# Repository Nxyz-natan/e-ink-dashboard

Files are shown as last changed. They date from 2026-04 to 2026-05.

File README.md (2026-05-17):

# e-ink-dashboard
e ink dashboard for me to display weather my room temp calander and date and time and disply my spotify 

Hardware Design

I designed a custom PCB that integrates:
ESP32-S3 microcontroller
BME280 sensor
Power management (voltage regulator + charging IC)
USB-C input
Display connector

Features

Real-time weather display
displays whats spotify playing
Room temperature and humidity using BME280 sensor
Calendar, date, and time display
Low power consumption using e-ink technology

here is my schematics 
Screenshot 2026-04-18 at 7 24 58 PM
here my pcb
Screenshot 2026-04-18 at 7 25 20 PM
here is my case 
Screenshot 2026-04-18 at 7 25 42 PM
## Bill of Materials

| Name | Purpose | Qty | Total Cost (USD) | Distributor |
|---|---|-----|---|---|
| 7.3" E Ink Spectra 6 Display 800x480 | Display | 1 | $47.34 | Good Display |
| Resistor 4.7kΩ 0402 | Resistor | 100 | $0.08 | LCSC |
| Pin Socket 1×08 2.54mm | Socket | 5 | $0.53 | LCSC |
|pcb | pcb | 5 | 3.50$ | jlcp |
| Switch 6×6×5mm | Button | 5 | $0.36 | LCSC |
| Resistor 1.2kΩ 0402 | Resistor | 100 | $0.09 | LCSC |
| BME280 | Temp/humidity sensor | 1 | $7.42 | LCSC |
| ME6211C33M5G-N | Voltage regulator | 10 | $0.50 | LCSC |
| TP4056-42-ESOP8 | Battery charger IC | 5 | $0.93 | LCSC |
| ESP32-S3-WROOM-1-N16R8 | MCU | 1 | $5.21 | LCSC |

**Total with shipping: 95.85$**

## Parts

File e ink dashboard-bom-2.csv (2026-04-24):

Name | Purpose | Quantity | Total Cost (USD) | Link | Distributor
3d printer | case |  | 15.00 |  | hackclub
pcb | pcb |  | 3.50 |  | jlcpcb
7.3-Inch Full Color E Ink Spectra 6 Display High-saturation 800x480 GDEP073E01 | display |  | 47.34 |  | good display
Switch 6x6x5mm | button | 5 | 0.36 |  | lcsc
ESP32-S3 N16R8 | chip | 1 | 5.21 |  | lcsc
Resistor 1.2kΩ 0402 | Resistor | 100 | 0.09 |  | lcsc
ME6211C33M5G-N | voltage regulator | 10 | 0.50 |  | lcsc
TP4056-42-ESOP8 | battery charger IC | 5 | 0.93 |  | lcsc
BME280 | temp reader | 1 | 7.42 |  | lcsc
Resistor 4.7kΩ 0402 | Resistor | 100 | 0.08 |  | lcsc
Pin Socket 1x08 2.54mm | Socket | 5 | 0.53 |  | lcsc

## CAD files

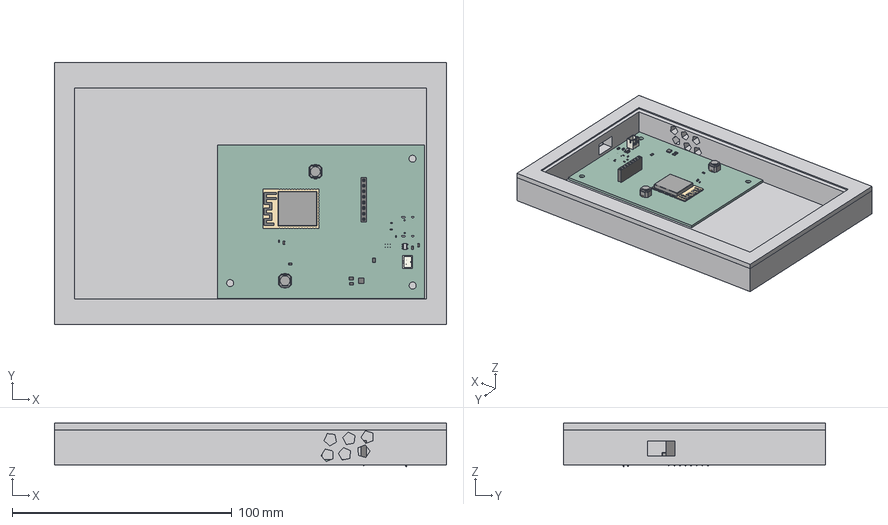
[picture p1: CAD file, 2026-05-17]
cad/e ink dahsboard lid with out a screen.step
178.2 x 119.2 x 19.8 mm
R_0402_1005Metric x 2
C_0402_1005Metric x 2
PinSocket_1x08_P2.54mm_Vertical x 3
R_0805_2012Metric x 27
SOT-23-5 x 5
pin_1 x 10
pin_2 x 10
JST_PH_B2B-PH-K_1x02_P2.00mm_Vertical x 5
C_0603_1608Metric x 3
ESP32-S3-WROOM-1 x 5
R_0603_1608Metric
Bosch_LGA-8_2.5x2.5mm_P0.65mm_ClockwisePinNumbering x 5
e-ink dashboard_PCB x 5
C_0805_2012Metric x 20
PinHeader_1x08_P2.54mm_Vertical x 2

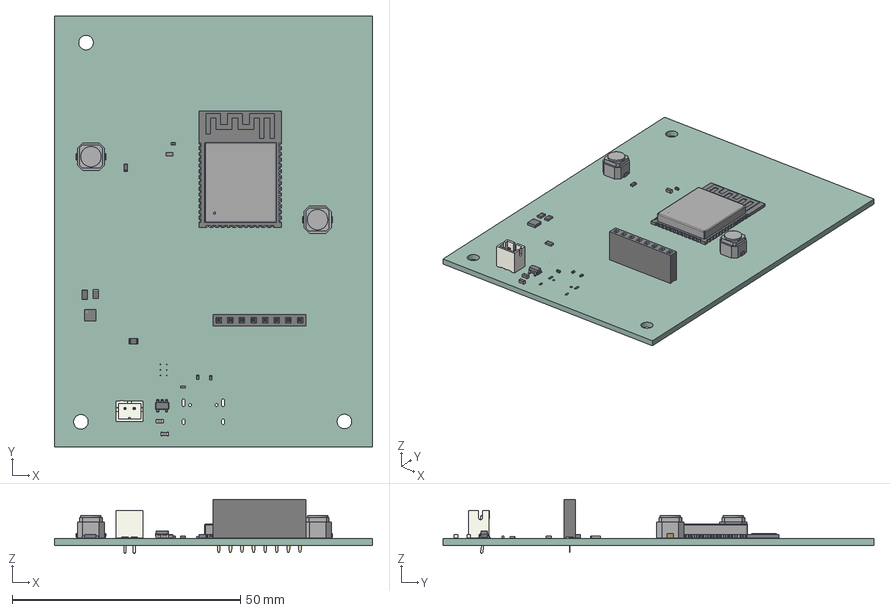
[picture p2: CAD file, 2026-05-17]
cad/pcbeink.step
69.6 x 94.2 x 11.9 mm
R_0402_1005Metric x 2
C_0402_1005Metric x 2
PinSocket_1x08_P2.54mm_Vertical
R_0805_2012Metric x 3
SOT-23-5
pin_1 x 2
pin_2 x 2
JST_PH_B2B-PH-K_1x02_P2.00mm_Vertical
C_0603_1608Metric x 3
ESP32-S3-WROOM-1
R_0603_1608Metric
Bosch_LGA-8_2.5x2.5mm_P0.65mm_ClockwisePinNumbering
e-ink dashboard_PCB

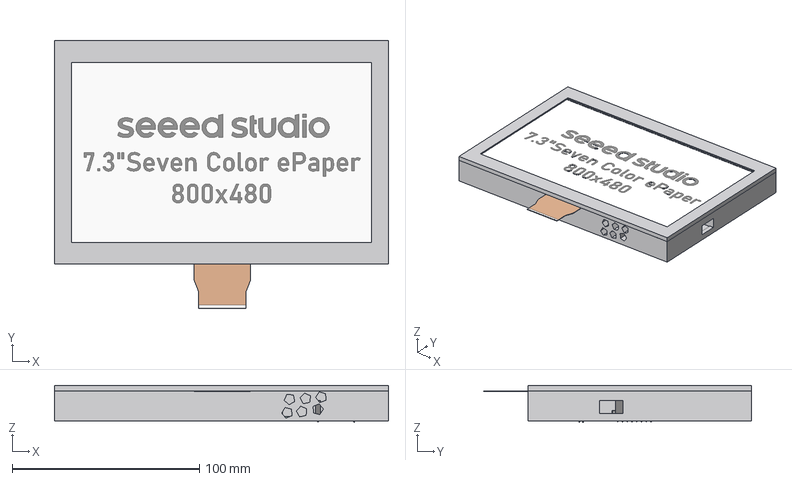
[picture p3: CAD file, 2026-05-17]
cad/e ink dahsboard with screen.step
178.2 x 142.8 x 19.8 mm
R_0402_1005Metric x 2
C_0402_1005Metric x 2
PinSocket_1x08_P2.54mm_Vertical x 3
R_0805_2012Metric x 27
SOT-23-5 x 5
pin_1 x 10
pin_2 x 10
JST_PH_B2B-PH-K_1x02_P2.00mm_Vertical x 5
C_0603_1608Metric x 3
ESP32-S3-WROOM-1 x 5
R_0603_1608Metric
Bosch_LGA-8_2.5x2.5mm_P0.65mm_ClockwisePinNumbering x 5
e-ink dashboard_PCB x 5
C_0805_2012Metric x 20
PinHeader_1x08_P2.54mm_Vertical x 2

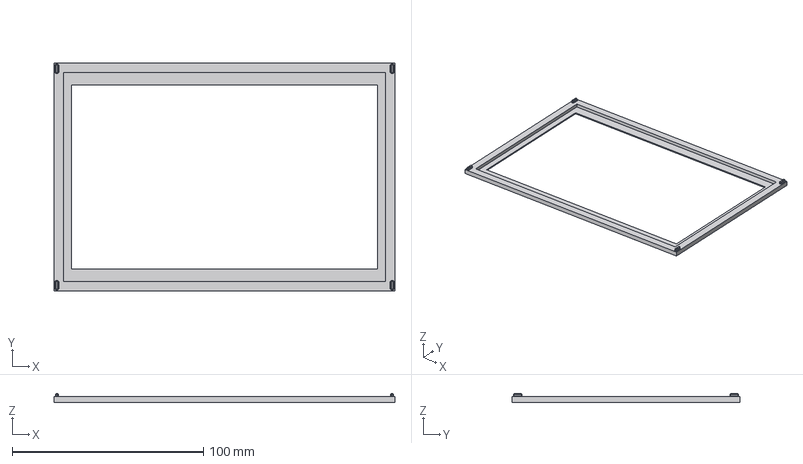
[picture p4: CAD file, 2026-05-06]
cad/e ink dahsboard lid.step
178.2 x 119.2 x 4.50 mm
R_0805_2012Metric x 12
C_0805_2012Metric x 10
PinSocket_1x08_P2.54mm_Vertical
SOT-23-5 x 2
pin_1 x 4
pin_2 x 4
JST_PH_B2B-PH-K_1x02_P2.00mm_Vertical x 2
ESP32-S3-WROOM-1 x 2
Bosch_LGA-8_2.5x2.5mm_P0.65mm_ClockwisePinNumbering x 2
e-ink dashboard_PCB x 2
PinHeader_1x08_P2.54mm_Vertical

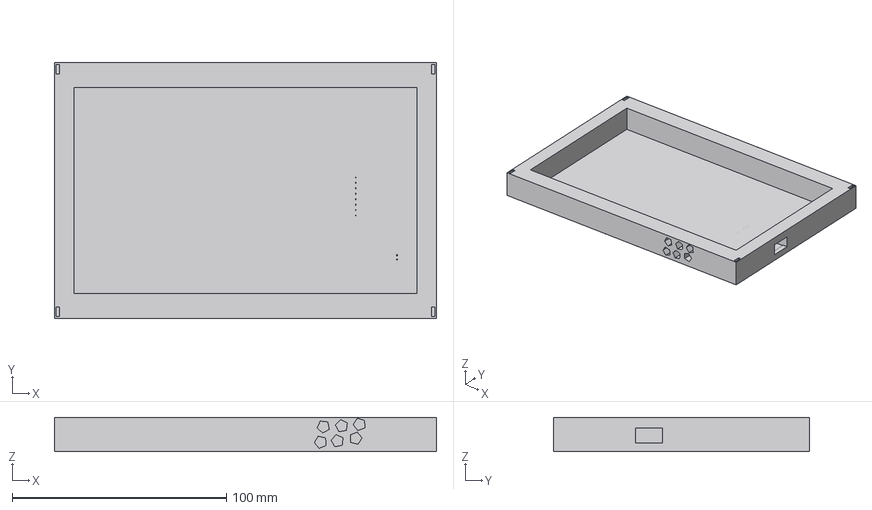
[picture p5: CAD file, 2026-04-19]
cad/case e ink.step
178.2 x 119.2 x 16.0 mm
R_0805_2012Metric x 12
C_0805_2012Metric x 10
PinSocket_1x08_P2.54mm_Vertical
SOT-23-5 x 2
pin_1 x 4
pin_2 x 4
JST_PH_B2B-PH-K_1x02_P2.00mm_Vertical x 2
ESP32-S3-WROOM-1 x 2
Bosch_LGA-8_2.5x2.5mm_P0.65mm_ClockwisePinNumbering x 2
e-ink dashboard_PCB x 2
PinHeader_1x08_P2.54mm_Vertical

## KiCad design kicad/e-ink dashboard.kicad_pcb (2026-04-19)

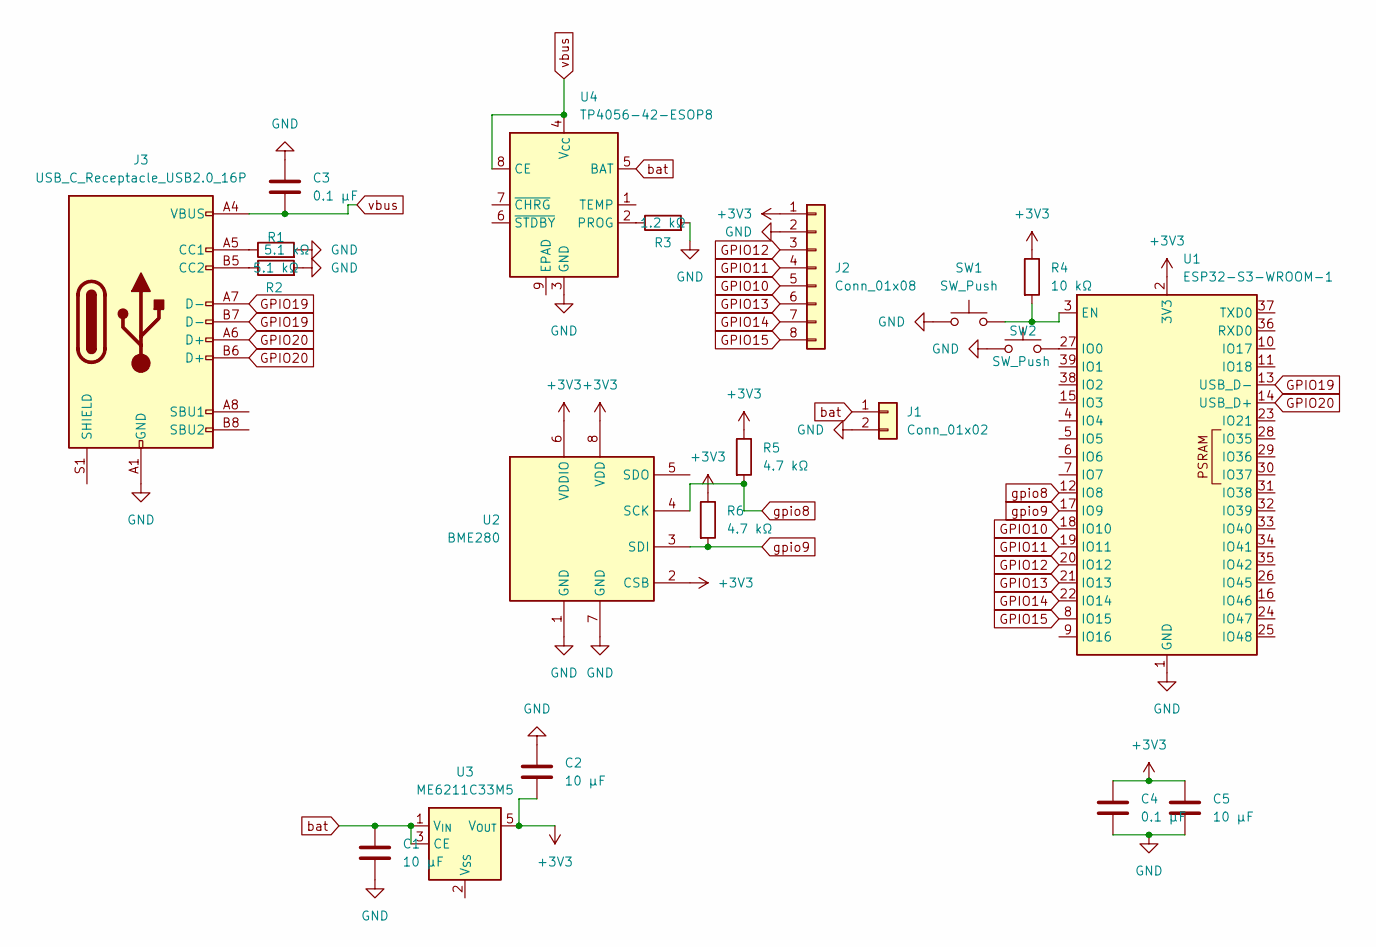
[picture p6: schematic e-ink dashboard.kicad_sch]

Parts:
C1, C2, C5: 10 µF; C_0603_1608Metric
C3, C4: 0.1 µF; C_0402_1005Metric
J1: Conn_01x02; JST_PH_B2B-PH-K_1x02_P2.00mm_Vertical
J2: Conn_01x08; PinSocket_1x08_P2.54mm_Vertical
J3: USB_C_Receptacle_USB2.0_16P; USB_C_Receptacle_HRO_TYPE-C-31-M-12
R1, R2: 5.1 kΩ; R_0402_1005Metric
R3: 1.2 kΩ; R_0805_2012Metric
R4: 10 kΩ; R_0603_1608Metric
R5, R6: 4.7 kΩ; R_0805_2012Metric
SW1, SW2: SW_Push; SW_Push_1TS009xxxx-xxxx-xxxx_6x6x5mm
U1: ESP32-S3-WROOM-1
U2: BME280; Bosch_LGA-8_2.5x2.5mm_P0.65mm_ClockwisePinNumbering
U3: ME6211C33M5; SOT-23-5
U4: TP4056-42-ESOP8; SOIC-8-1EP_3.9x4.9mm_P1.27mm_EP2.41x3.3mm_ThermalVias

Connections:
+3V3: C2.2, C4.1, C5.1, J2.1, R4.1, R5.1, R6.1, U1.2 (3V3), U2.2 (CSB), U2.6 (VDDIO), U2.8 (VDD), U3.5 (V_{OUT})
GND: C1.1, C2.1, C3.1, C4.2, C5.2, J1.2, J2.2, J3.A1 (GND), J3.A12 (GND), J3.B1 (GND), J3.B12 (GND), R1.2, R2.2, R3.2, SW1.1, SW2.1, U1.1 (GND), U1.40 (GND), U1.41 (GND), U2.1 (GND), U2.7 (GND), U4.3 (GND)
GPIO10: J2.5, U1.18 (IO10)
GPIO11: J2.4, U1.19 (IO11)
GPIO12: J2.3, U1.20 (IO12)
GPIO13: J2.6, U1.21 (IO13)
GPIO14: J2.7, U1.22 (IO14)
GPIO15: J2.8, U1.8 (IO15)
GPIO19: J3.A7 (D-), J3.B7 (D-), U1.13 (USB_D-)
GPIO20: J3.A6 (D+), J3.B6 (D+), U1.14 (USB_D+)
unnamed: J3.A5 (CC1), R1.1
unnamed: J3.B5 (CC2), R2.1
unnamed: R4.2, SW1.2, U1.3 (EN)
unnamed: SW2.2, U1.27 (IO0)
unnamed: R3.1, U4.2 (PROG)
bat: C1.2, J1.1, U3.1 (V_{IN}), U3.3 (CE), U4.5 (BAT)
gpio8: R5.2, U1.12 (IO8), U2.4 (SCK)
gpio9: R6.2, U1.17 (IO9), U2.3 (SDI)
vbus: C3.2, J3.A4 (VBUS), J3.A9 (VBUS), J3.B4 (VBUS), J3.B9 (VBUS), U4.4 (V_{CC}), U4.8 (CE)

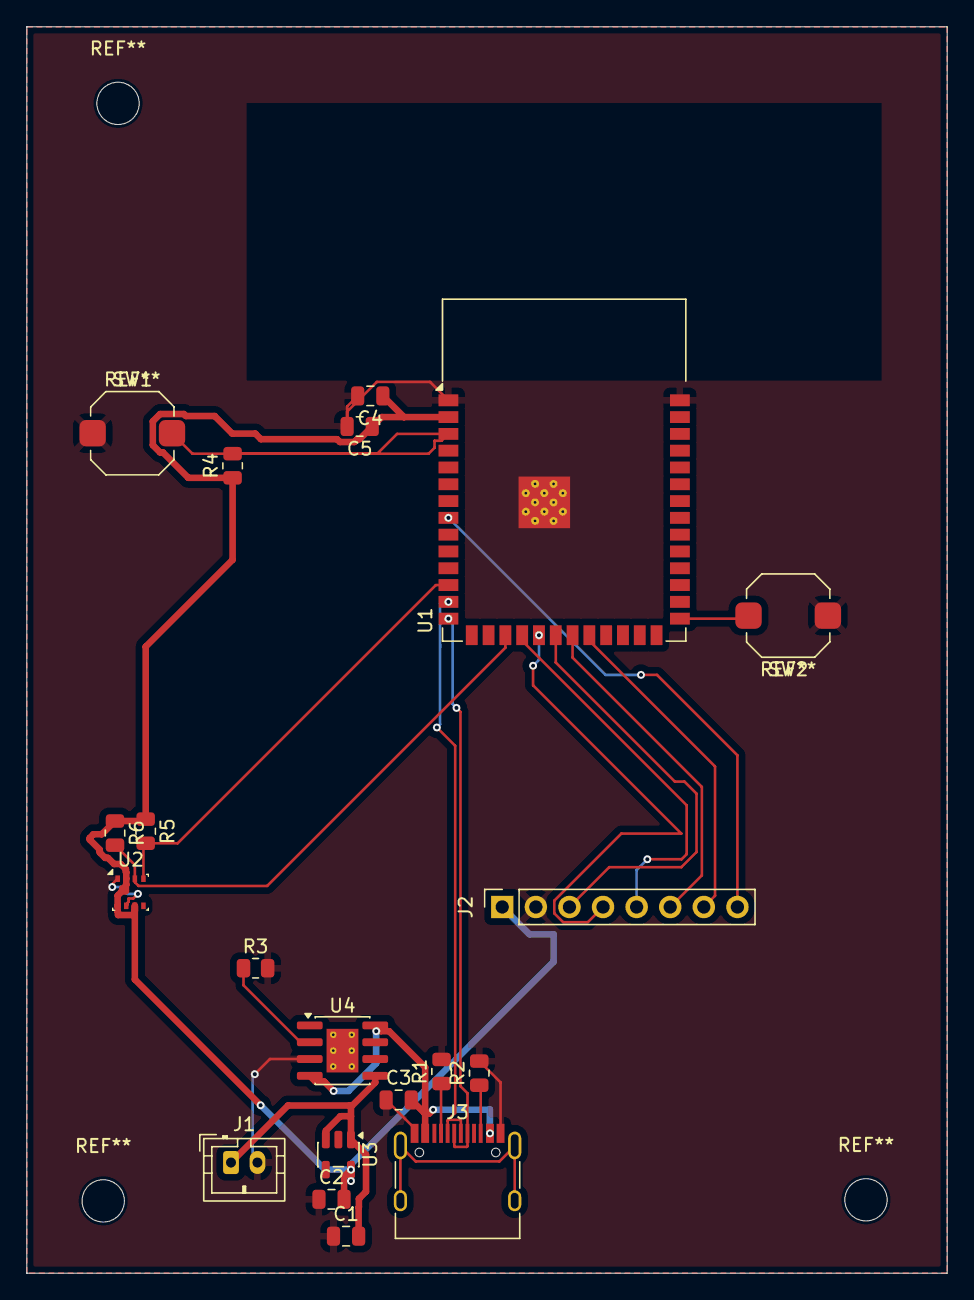
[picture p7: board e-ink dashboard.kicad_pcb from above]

Board: 2 copper layers, 69.6 x 94.2 mm, 20 parts (0 on the bottom side), 19 nets.

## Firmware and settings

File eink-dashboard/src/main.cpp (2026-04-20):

#include <Arduino.h>
#include <WiFi.h>
#include <SPI.h>
#include <time.h>

#include "config.h"
#include "display_driver.h"
#include "weather.h"
#include "spotify.h"

// Global objects
EpaperDisplay display;
WeatherClient weather(WEATHER_API_KEY, WEATHER_CITY, WEATHER_COUNTRY);
SpotifyClient spotify(SPOTIFY_CLIENT_ID, SPOTIFY_CLIENT_SECRET);

// Timing
unsigned long lastWeatherUpdate = 0;
unsigned long lastSpotifyUpdate = 0;
unsigned long lastClockUpdate = 0;
unsigned long lastFullRefresh = 0;

// State tracking
bool nothingPlaying = false;
const unsigned long FULL_REFRESH_INTERVAL = 300000;  // Full refresh every 5 min

void connectWiFi() {
    Serial.println("Connecting to WiFi...");
    WiFi.begin(WIFI_SSID, WIFI_PASSWORD);

    int attempts = 0;
    while (WiFi.status() != WL_CONNECTED && attempts < 30) {
        delay(500);
        Serial.print(".");
        attempts++;
    }

    if (WiFi.status() == WL_CONNECTED) {
        Serial.println("\nWiFi connected!");
        Serial.println("IP: " + WiFi.localIP().toString());
    } else {
        Serial.println("\nWiFi connection failed!");
    }
}

void syncTime() {
    configTime(0, 0, NTP_SERVER);
    setenv("TZ", TIMEZONE, 1);
    tzset();

    struct tm timeinfo;
    int attempts = 0;
    while (!getLocalTime(&timeinfo) && attempts < 10) {
        delay(500);
        attempts++;
    }
}

String formatTime(time_t now) {
    char buffer[6];
    struct tm* timeinfo = localtime(&now);
    strftime(buffer, 6, "%H:%M", timeinfo);
    return String(buffer);
}

String formatDate(time_t now) {
    char buffer[20];
    struct tm* timeinfo = localtime(&now);
    strftime(buffer, 20, "%A, %b %d", timeinfo);
    return String(buffer);
}

void drawClock(time_t now) {
    auto* g = display.getDisplay();
    // Large clock centered
    g->setFont(&FreeMonoBold24pt7b);
    g->setCursor(50, 100);
    g->print(formatTime(now));

    g->setFont(&FreeMono12pt7b);
    g->setCursor(50, 145);
    g->print(formatDate(now));

    // Separator line
    g->drawLine(50, 160, 750, 160, GxEPD2_3C::BLACK);
}

void drawWeather() {
    auto* g = display.getDisplay();
    g->setFont(&FreeMonoBold12pt7b);
    g->setCursor(50, 200);
    g->print("Weather");

    if (weather.isValid()) {
        WeatherData data = weather.getData();
        g->setFont(&FreeMono18pt7b);
        g->setCursor(50, 250);
        g->print(data.temperature, 0);
        g->print(" C");

        g->setFont(&FreeMono9pt7b);
        g->setCursor(200, 255);
        g->println(data.description);

        g->setCursor(50, 285);
        g->print("Humidity: ");
        g->print(data.humidity);
        g->print("%  |  Wind: ");
        g->println(data.windSpeed);
    } else {
        g->setFont(&FreeMono9pt7b);
        g->setCursor(50, 250);
        g->println("Loading...");
    }
}

void drawSpotify() {
    auto* g = display.getDisplay();
    g->setFont(&FreeMonoBold12pt7b);
    g->setCursor(50, 340);
    g->print("Now Playing");

    if (spotify.isValid()) {
        SpotifyData data = spotify.getData();
        g->setFont(&FreeMono12pt7b);
        g->setCursor(50, 385);
        g->print(data.isPlaying ? "> " : "|| ");
        g->println(data.trackName);

        g->setFont(&FreeMono9pt7b);
        g->setCursor(70, 415);
        g->print("by ");
        g->println(data.artistName);
    } else {
        g->setFont(&FreeMono9pt7b);
        g->setCursor(50, 385);
        g->println("No playback");
    }
}

void drawCalendar() {
    // Placeholder - calendar skipped for now
    // Could add quotes, stock ticker, or other info here
}

void drawFullDisplay() {
    display.clear();

    time_t now = time(nullptr);
    drawClock(now);
    drawWeather();
    drawSpotify();

    display.display();
}

void setup() {
    Serial.begin(115200);
    Serial.println("E-Ink Dashboard Starting...");

    // Initialize display
    Serial.println("Initializing display...");
    display.begin();
    display.setRotation(1);  // Landscape orientation
    display.setFullWindow();

    // Connect to WiFi
    connectWiFi();

    // Sync time
    syncTime();

    // Initial updates
    Serial.println("Performing initial updates...");
    weather.update();
    spotify.update();

    // Draw everything
    drawFullDisplay();

    lastFullRefresh = millis();
    Serial.println("Setup complete!");
}

void loop() {
    unsigned long now = millis();
    bool needsRefresh = false;

    // Weather update (every 15 min)
    if (now - lastWeatherUpdate >= WEATHER_REFRESH_INTERVAL * 1000) {
        if (weather.update()) {
            lastWeatherUpdate = now;
            Serial.println("Weather updated");
            needsRefresh = true;
        }
    }

    // Spotify update - dynamic interval based on playback state
    unsigned long spotifyInterval = spotify.getRefreshInterval();
    if (now - lastSpotifyUpdate >= spotifyInterval) {
        if (spotify.update()) {
            lastSpotifyUpdate = now;
            Serial.println("Spotify state changed - refreshing display");
            needsRefresh = true;
        }
    }

    // Clock update (every minute)
    if (now - lastClockUpdate >= CLOCK_REFRESH_INTERVAL * 1000) {
        lastClockUpdate = now;
        // Time display updates with full refresh
    }

    // Periodic full refresh to prevent ghosting (every 5 min)
    if (now - lastFullRefresh >= FULL_REFRESH_INTERVAL) {
        Serial.println("Periodic full refresh");
        needsRefresh = true;
        lastFullRefresh = now;
    }

    // Refresh display if needed
    if (needsRefresh) {
        drawFullDisplay();
    }

    // Deep sleep if configured
    if (DEEP_SLEEP_DURATION > 0) {
        esp_sleep_enable_timer_wakeup(DEEP_SLEEP_DURATION * 1000000ULL);
        esp_deep_sleep_start();
    }

    delay(1000);
}

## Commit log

2026-05-08 Rename e-ink dashboard.kicad_sch to kicad/e-ink dashboard.kicad_sch
    [e-ink dashboard.kicad_sch]
2026-05-08 Rename e-ink dashboard.kicad_pro to kicad/e-ink dashboard.kicad_pro
2026-05-08 Rename e-ink dashboard.kicad_pcb to kicad/e-ink dashboard.kicad_pcb
    [e-ink dashboard.kicad_pcb]
2026-05-08 Rename Archive.zip to pcb production/Archive.zip
2026-05-08 Rename bottom case e ink.shapr to cad/bottom case e ink.shapr
2026-05-08 Rename case e ink.step to cad/case e ink.step
    [case e ink.step]
2026-05-08 Rename e ink dahsboard lid.step to cad/e ink dahsboard lid.step
    [e ink dahsboard lid.step]
2026-05-08 Rename new top.step to cad/new top.step
    [new top.step]
2026-05-08 Rename top lid e ink.shapr to cad/top lid e ink.shapr
2026-05-08 Rename e ink dashboard-bom-2.csv to BOM/e ink dashboard-bom-2.csv
    [e ink dashboard-bom-2.csv]
